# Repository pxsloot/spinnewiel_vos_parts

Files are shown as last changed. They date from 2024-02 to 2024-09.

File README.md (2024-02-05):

# Parts for VO&S spinningwheel

Designer Sebastiaan Vos had his own ideas about spinning wheels and designed
and built a tower model spinning wheel stripped to its essence, with a few
clever details.

I found my own VO&S in a kringloop, with only one bobbin. The flight had random
bits of hardware for leading the yarn on the bobbin. After a short while things
started breaking and ergonomics wheren't great so I came up with this.

So here is the openscad script to generate an stl file. Use 100% infill when
printing to make the part more robust. There's some forces involved when
spinning yarn.

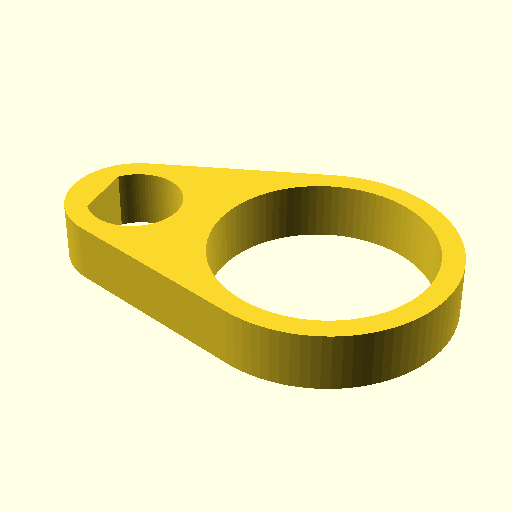
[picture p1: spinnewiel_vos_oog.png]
eyelet preview


You need to balance the flight with M6/M7washers and M7 nuts. Being a tower
model, any unbalance in the top will be amplified on the floor. Your neighbours
will notify you if you forget to balance. Think 90's harddisk in top of your
maxi tower pc.  Balancing can be done with M6/M7washers and M7 nuts. Keep the
weights between 2 eyelets.

Thickness can be adjusted with variable 'hoogte'
Yarn ring size can be adjusted with variable 'ring_id'

## part to keep balance weights in place

Obviously based on the eyelet.

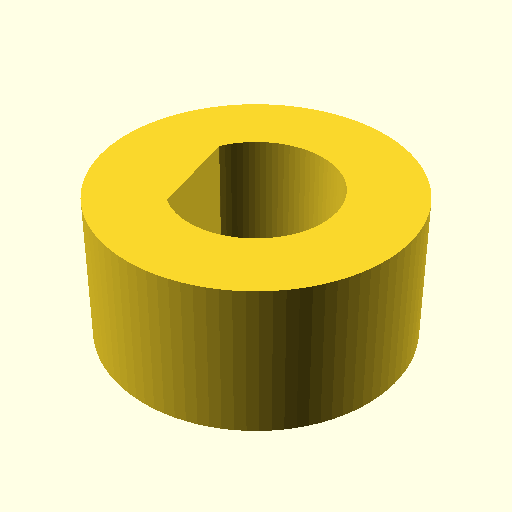
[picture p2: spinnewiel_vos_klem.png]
part preview


## bushing for double drive

A mystery part was missing from the double drive. According to the
measurements it could have been something like this

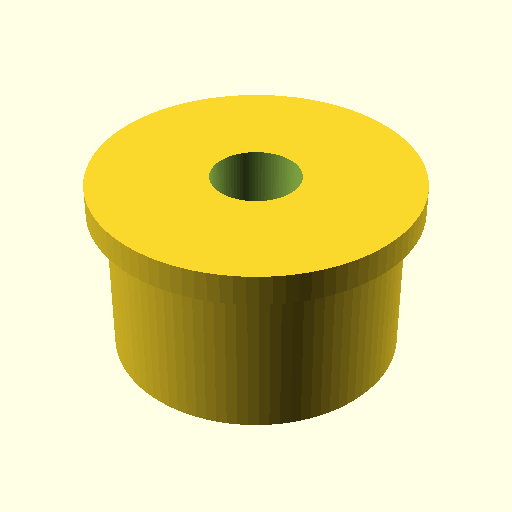
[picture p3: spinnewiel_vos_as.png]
as preview


# generate STL files

```
  $ make
```

# bc script to figure out what's what with triangles and parallels

I studied https://unixwars.blogspot.com/2016/03/joining-two-circlescylinders-in.html
and used below bc script to get things right. The sketch I used was made in
excalidraw.

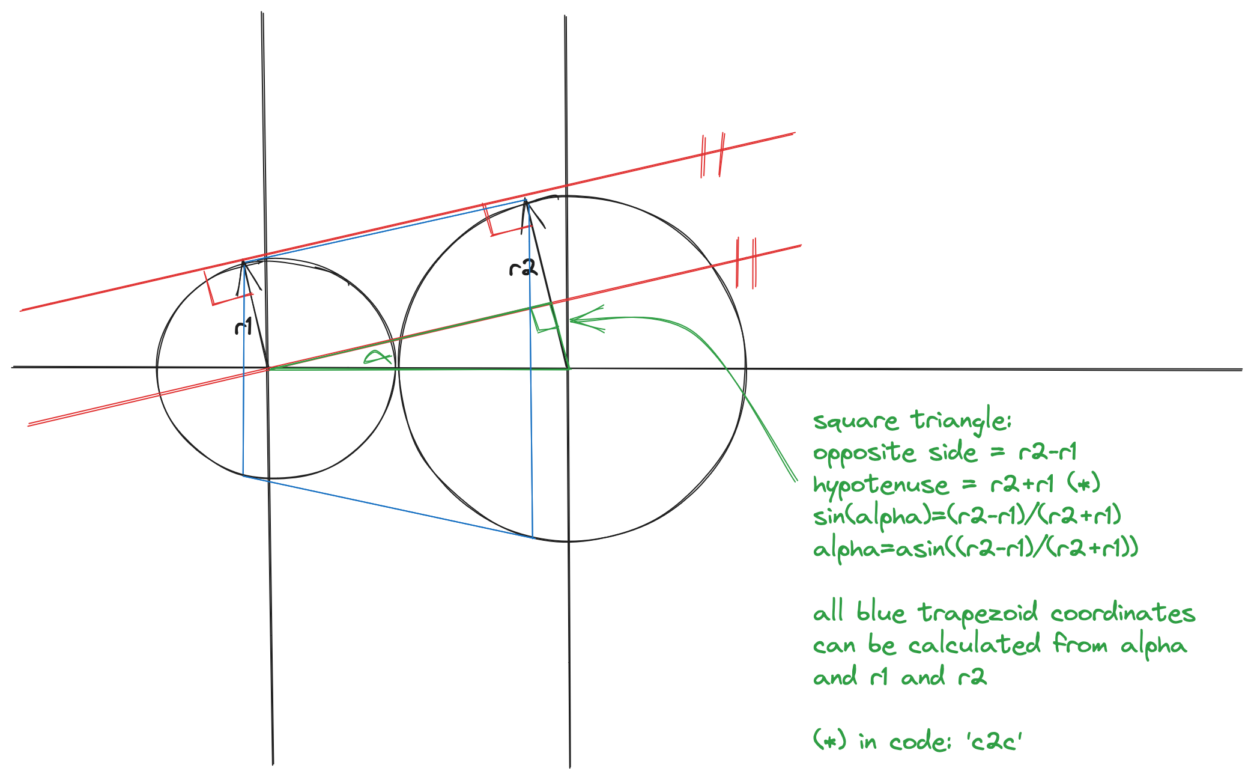
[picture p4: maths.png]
Maths


```bc
define asin(x) {
  if(x==1) return(pi/2)
  if(x==-1) return(-pi/2)
  return(a(x/sqrt(1-(x^2))))
}

vlucht_dia=6.5
vlucht_vlak=.5

bus_dikte=3
bus_id=vlucht_dia
bus_od=bus_id+bus_dikte

ring_dikte=bus_dikte
ring_id=15
ring_od=ring_id+ring_dikte

c2c = (bus_od+ring_od)/2

r1 = bus_od/2
r2 = ring_od/2

alpha = asin((r2-r1)/c2c)
x1 = r1*s(alpha)
y1 = r1*c(alpha)
x2 = c2c-r2*s(alpha)
y2 = r2*c(alpha)
```

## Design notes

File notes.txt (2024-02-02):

# Eyelet for VO&S spinningwheel

Designer Sebastiaan Vos had his own ideas about spinning wheels and designed
and built a tower model spinning wheel stripped to its essence, with a few
clever details that show Vos really understands the craft of fiber spinning.

I found my own one in a kringloop, with only one bobbin and pieces of hardware
for leading the yarn along the flight. After a short while things started
falling off and breaking and it became apparent that I needed to come up with
something better.

So here is the openscad script to generate an stl file. When slicing, fill it
100% to prevent breaking. There's some forces involved when spinning yarn.

You need to balance the flight with M6/M7washers and M7 nuts. Being a tower
model, any unbalance in the top will be amplified on the floor. Your neighbours
will notify you if you forget.  Think 90's harddisk in top of your maxi tower
pc.  Balancing can be done with M6/M7washers and M7 nuts. Keep the weights
between 2 eyelets.

Thickness can be adjusted with variable 'hoogte'
Yarn ring size can be adjusted with variable 'ring_id'

# generate STL file

```
  $ openscad -o spinnewiel_oog.stl spinnewiel_oog.scad
```

# bc script to figure out what's what with triangles and parallels

I adapted some code from https://unixwars.blogspot.com/2016/03/joining-two-circlescylinders-in.html
and used below bc script to get things right.

---
define asin(x) {
  if(x==1) return(pi/2)
  if(x==-1) return(-pi/2)
  return(a(x/sqrt(1-(x^2))))
}

vlucht_dia=6.5
vlucht_vlak=.5

bus_dikte=3
bus_id=vlucht_dia
bus_od=bus_id+bus_dikte

ring_dikte=bus_dikte
ring_id=15
ring_od=ring_id+ring_dikte

c2c = (bus_od+ring_od)/2

r1 = bus_od/2
r2 = ring_od/2

a1 = c2c*r2/(r2 - r1)
alpha = asin(r2/a1)
#    alpha = asin((r2+r1)/(r2-r1))
x1 = r1*s(alpha)
y1 = r1*c(alpha)
x2 = c2c-r2*s(alpha)
y2 = r2*c(alpha)

---

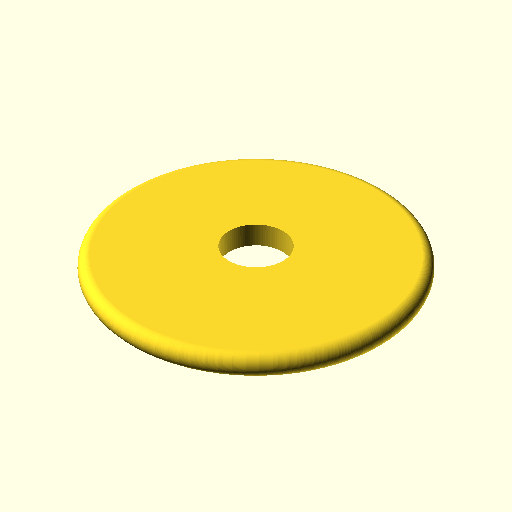
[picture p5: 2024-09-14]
spinnewiel_vos_bobbin_small_end.png

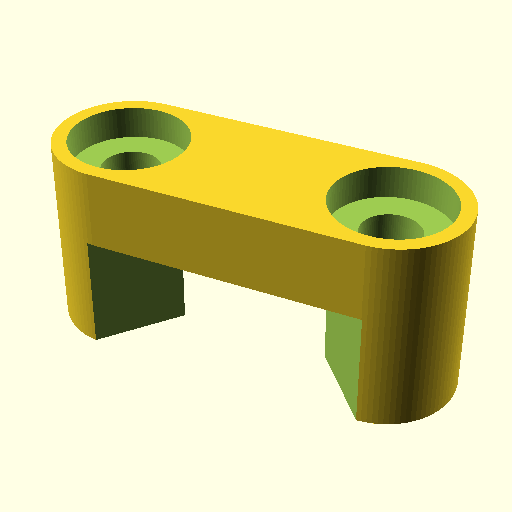
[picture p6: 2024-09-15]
spinnewiel_vos_treadle_fastener.png

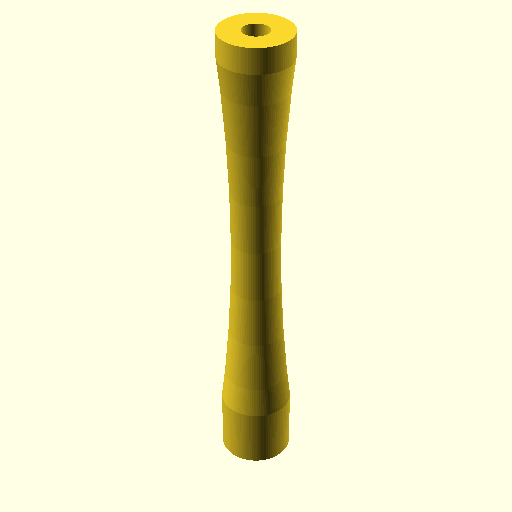
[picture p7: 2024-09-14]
spinnewiel_vos_bobbin_axle.png

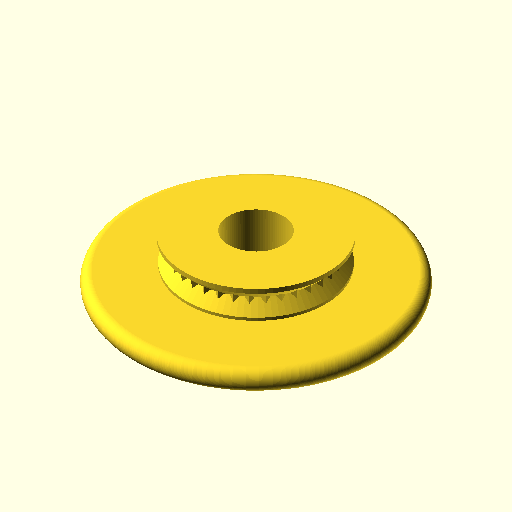
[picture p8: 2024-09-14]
spinnewiel_vos_bobbin_big_end.png

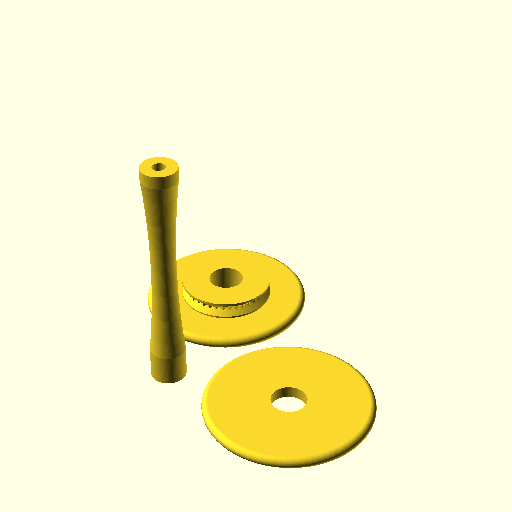
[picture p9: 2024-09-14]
spinnewiel_vos_bobbin.png

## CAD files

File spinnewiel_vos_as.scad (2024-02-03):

// bus voor de as van een VO&S spinnewiel aandrijving
// buiten diameter 19.5
// binnen diameter 6 == vlucht arm diameter
// hoogte 11

$fn = 90;

difference() {
  union() {
    cylinder(h=11,d=19.5);
    translate([0,0,10.5])
      cylinder(h=2,d=22);
  };
  cylinder(h=20,d=6);
}

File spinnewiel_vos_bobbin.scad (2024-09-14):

$fn = 90;

// VO&S bobbin recreated from measurements

axle_length = 127.5;
axle_diameter = 19;
axle_min_width = 13;
axle_hole = 7;

bobbin_side_r=90;

pulley_width = 10;
pulley_diameter = 50;
pulley_r = pulley_diameter/2;

small_end = 6.5;
big_end = small_end + pulley_width;


include <spinnewiel_vos_bobbin_parts.scad>;

//translate([70,0,small_end/2]) bobbin_end();
//translate([0,70,0]) bobbin_big_end();
//translate([0,0,axle_length/2]) bobbin_axle();


// uncomment to build
//bobbin_end();
//bobbin_big_end();
//bobbin_axle();

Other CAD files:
spinnewiel_vos_bobbin_axle.scad
spinnewiel_vos_bobbin_big_end.scad
spinnewiel_vos_bobbin_parts.scad
spinnewiel_vos_bobbin_small_end.scad
spinnewiel_vos_klem.scad
spinnewiel_vos_oog.scad
spinnewiel_vos_treadle_fastener.scad

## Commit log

2024-02-02 Last step of dev is to create a repo
    This item is finished, so initial commit.
    [spinnewiel_oog.scad]
2024-02-02 found a better triangle
    unix wars had me on the right track, but did some funky mathgic I couldn't
    figure out. Made a simpler spell
    [spinnewiel_oog.scad]
2024-02-02 glad I made a sketch
    atan/asin. Needed to dust of some trig
    [spinnewiel_oog.scad]
2024-02-03 edit comments
    [spinnewiel_oog.scad]
2024-02-03 add another part
    print it twice to keep balancing weights in place
    got a bit better at maths
    [spinnewiel_vos_klem.scad, spinnewiel_vos_oog.scad]
2024-02-03 add another part
    forgot about this one.
    [spinnewiel_vos_as.scad]
2024-03-05 M8 seems to fit best
    [spinnewiel_vos_oog.scad]
2024-07-31 make oog ready for thingiverse
    [spinnewiel_vos_oog.scad]
2024-07-31 make ready for thingiverse
    [spinnewiel_vos_klem.scad]
2024-09-09 add part bobbin
    [spinnewiel_vos_bobbin.scad, spinnewiel_vos_bobbin_parts.scad]
2024-09-14 add notches to pulley for more grip
    [spinnewiel_vos_bobbin.scad, spinnewiel_vos_bobbin_parts.scad]
2024-09-14 add fastener for treadle plank
    [spinnewiel_vos_treadle_fastener.scad]
2024-09-14 rearrange bobbin and parts, rename end to small_end
    [spinnewiel_vos_bobbin_axle.scad, spinnewiel_vos_bobbin_big_end.scad, spinnewiel_vos_bobbin_parts.scad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]
2024-09-14 make all part stl and png files
2024-09-14 clean up code before committing
    [spinnewiel_vos_treadle_fastener.scad]
